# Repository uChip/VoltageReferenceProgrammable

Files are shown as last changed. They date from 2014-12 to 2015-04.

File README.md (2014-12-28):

Programmable Voltage Reference  
==============================

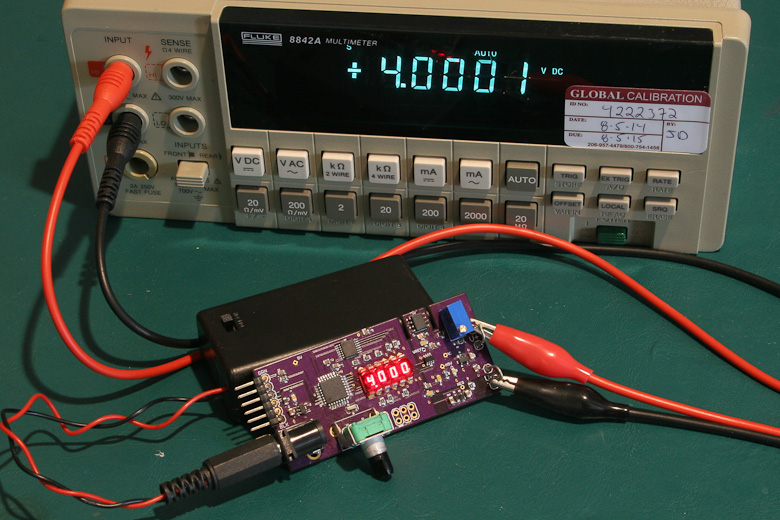
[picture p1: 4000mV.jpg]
Programmable Voltage Reference with 1 mV resolution and 100 uV accuracy
  
This repository contains the design files and write-up for a Programmable Voltage Reference.  The reference has a range of 1 mV to 4.095 volts in 1 mV steps.  The accuracy is plus or minus 100 uV for any set value.  The reference value is displayed on a 4 digit LED display and can be set manually using the rotary encoder or remotely over serial (FTDI port).

The software folder contains an Arduino sketch that is source code for the voltage reference firmware.

See the file PVR.pdf for a more detailed explanation of the project design. 

If there is sufficient interest I will build and calibrate a batch of these to sell.  If you would like one, please contact me. 

## Order PCBs  

You can order this PCB directly from OSH Park.  Click on the following link.  
  * Programmable Voltage Reference - https://oshpark.com/shared_projects/aFUNW4O5 

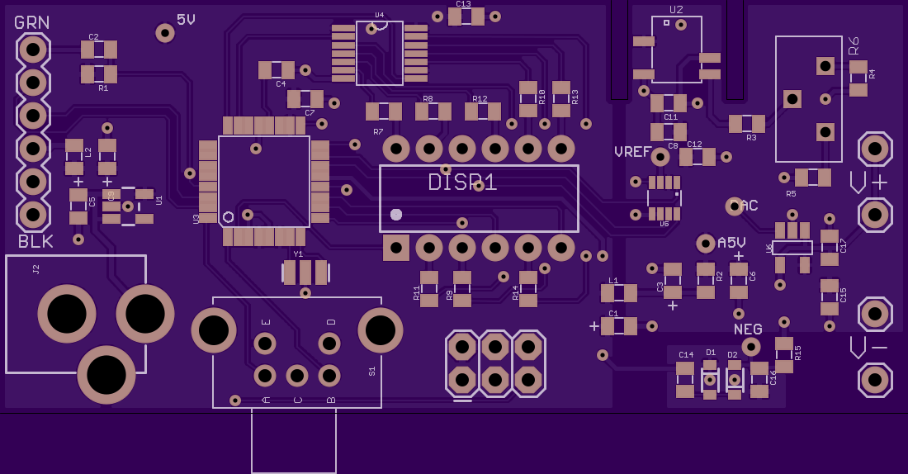
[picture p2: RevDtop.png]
PCB Top


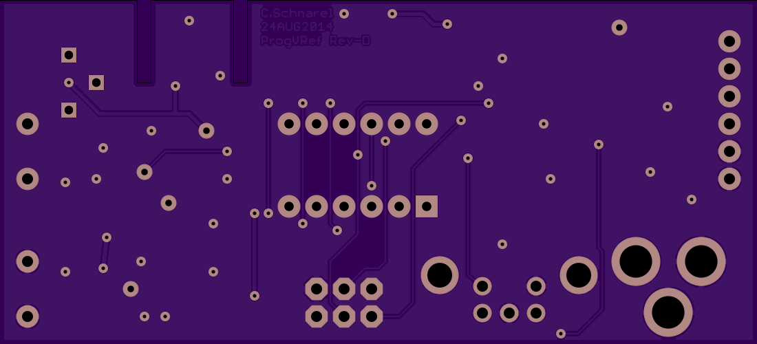
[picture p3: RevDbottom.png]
PCB Bottom


See the Bill of Materials (BOM) file in the repo Hardware folder for a parts list.  

## Status  
  * Rev-D PCB has been tested to be functional.  

## File Formats  

Hardware design files are in "CadSoft EAGLE PCB Design Software" .brd and .sch formats.  A free version of the software can be downloaded from www.cadsoftusa.com. 

The example code is in Arduino .ino format (text).  A free version of the Arduino software can be downloaded from www.arduino.cc.  

## Distribution License  

License:
<br /><span xmlns:dct="http://purl.org/dc/terms/" property="dct:title">Programmable Voltage Reference</span> by <a xmlns:cc="http://creativecommons.org/ns#" href="https://github.com/uChip/VoltageReferenceProgrammable" property="cc:attributionName" rel="cc:attributionURL">C.Schnarel</a> is licensed under a <a rel="license" href="http://creativecommons.org/licenses/by-sa/4.0/">Creative Commons Attribution-ShareAlike 4.0 International License</a>.

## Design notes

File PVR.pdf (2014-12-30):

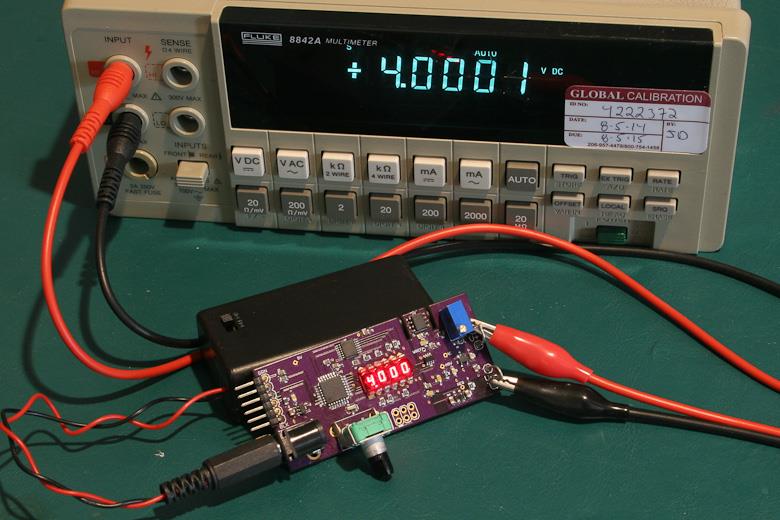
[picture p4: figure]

Programmable Voltage Reference with 1 mV resolution and 100 uV accuracy

Over the last few months I've done a few projects that made use of the analog inputs on the Arduino/ATmega processor. I found that trying to debug the software at the same time as debugging and calibrating the hardware was cumbersome (to put it mildly). The more I dealt with this, the more I thought that a programmable voltage reference would simplify things. With a programmable reference I could simulate an analog sensor input and debug the software without worrying about whether the sensor hardware is working or not. The voltage reference makes it easier to manipulate the input, test boundary conditions or check the accuracy of the ADC.

Consider this example of a simple temperature probe. The probe uses an ATtiny85 8-pin processor connected to an LMT84 analog temperature sensor and two LEDs, one red and one green. As long as the temperature stays in range the green LED flashes once every 15 seconds. If the temperature goes out of range, either high or low, for more than a few samples the red LED flashes instead until the unit is reset. The whole thing is powered by a coin cell and physically is about the size of the cell holder and twice as thick. The battery needs to last for a few months.

The design is simple, but has a couple of tricky aspects. How do you debug a processor that has no serial port and is asleep most of the time? There weren't even any spare pins to send out debug signals. The processor controls the power to the sensor so that's not on all the time either. The sensor is putting out a signal only one millisecond out of every 15,000. Measuring that is a tough job for a DMM or for my old analog scope. And even if you assume the sensor is working perfectly how do you manipulate the sensor accurately to test the range thresholds?

By substituting a voltage reference for the sensor the development is simplified. By supplying a known voltage to the ADC input I can debug the software by writing test code to flash the LEDs and get the ADC working right. Once I know I'm getting good readings I can then vary the reference input through a range of values to check that the software handles all input values correctly and triggers when it should. Once I know the ADC is reading correctly and the software is doing the right thing with the ADC values, I can put the sensor back in the circuit and verify it using the software.

So having decided that a voltage reference would be a good thing to have, I looked around on eBay and other places. I don't seem to have Dave Jones' eBay luck. (http://www.eevblog.com/2011/10/24/eevblog-210-krohn-hite-dc-voltage-standard-teardown-calibration/) Everything I could find was hundreds of dollars. I don't have that much to spend, so instead I decided to build my own.

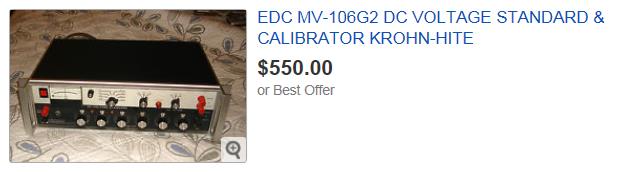
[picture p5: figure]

Example Voltage Standard posting on eBay

I need to go on a tangent here for a moment. I keep using the term voltage reference. If you do a search for voltage reference on eBay, or your favorite parts supplier, you will get lots of hits and what you find will cost only a few dollars. However, most of these provide only a single voltage and have accuracies in the 0.05% range. That means that at 4 volts they could be off by as much as 2 mV. I’d like something that is accurate to at least 100 uV or about twenty times better. The things that I’m talking about and what Dave Jones has are called voltage standards and can be set for many different values. The difference is that a voltage standard has been calibrated to a particular accuracy specification using an instrument that has been certified to have an even higher accuracy (typically ten times higher accuracy). And that instrument has been calibrated by an instrument certified to higher accuracy yet. This “chain of trust” goes back all the way to some standards body that holds the absolute gold standard for that particular chain. The best meter that I own is a 5 ½ digit (200,000 count) Fluke. It has been calibrated by a certified calibration lab so I have access to that chain of trust. And while I think I can achieve the level of accuracy I want, it might be presumptuous of me to call my device a voltage standard. So I’ll keep calling it a reference even though I hope it behaves like and I can use it like a standard.

Getting back to the design of the device: The goal would be to set voltages with the same or better resolution than the ATmega's ADC input across a reasonable input range. Since the ADC is 10 bit it has 1024 levels. If you choose the band-gap reference for the ADC, that's roughly 1 millivolt resolution. If instead we choose AVcc as the reference the resolution would be ~5 mV (on a 5 V system), but let's shoot for 1 mV across the whole range. A nice round number for the range would be 4.095 volts. That's 12-bits worth of 1 mV steps. For accuracy, I'd like when I set the reference to 1.234 mV that it be significantly closer to that value than to 1.233 or 1.235. Same thing when I set the value to 0.005 or 4.095. Let's call it within 100 uV of the target value. Of course, accuracy and resolution are no good if there's too much noise, so it must be low noise as well. This is a voltage reference, not a power supply, so a limit of a few milliamps is acceptable. The last spec is budget. As I said voltage standards on eBay go for hundreds of dollars. I am targeting a budget of $50 parts cost.

A voltage reference is really a simple device. In fact it could be as simple as a potentiometer and an OpAmp. Hook the output of the OpAmp to a good voltmeter and set the voltage level you need using the pot. But that ties up the meter and setting the pot to millivolt values across a multi-volt scale is at best fiddly. So let's complicate things a bit. Let's make the selection digital and include a 4-digit LED display. If we build the control around an Arduino core, the software development is simpler, plus we can re-use the programming serial port for remote control.

Interestingly enough, though I've finished project already, I just recently watched Ian Johnson's video (http://ianjohnston.com/index.php?option=com_content&view=article&id=108) on hacking a voltage standard he bought on eBay. Inside his EDC 501J I expected to see a high end integrated precision DAC. Instead what was inside was a DAC built from discrete resistors and many more trim pots than I expected. The expense must have been in trimming all those resistors!

I want to be able to calibrate as well, but let's hold that to a single trim pot and do the rest in software. For the core of my design I chose the REF5040ID voltage reference chip paired with the AD5060BRJZ DAC. I chose the 5040 because it starts with good accuracy, good temperature stability, good aging and is trimmable. The 5040 is accurate to 0.05% or about 2 mV, but has a trim input. By using a trimmable reference I should be able to get the error well under 1 mV. The 5060 is a 16-bit DAC with plus or minus 2 LSB relative accuracy (INL) and 1 LSB differential nonlinearity (DNL). If you recall, the output resolution needs to be 12 bits. By using a 16-bit DAC the output can be set to the proper 12-bit value and then calibrated with another 4 bits. If the 12-bit step is 1 mV then 4 more bits is 1/16 or 0.0625 mV which should enable me to calibrate to well within the spec. Note that together these two parts are over $20. They are relatively expensive compared to the microcontroller, display or even the PCB, but since they also are the heart of the device I think they are worth it.

All of the rest of the circuitry is there to provide the control interface and to support those two chips. There is a voltage-follower OpAmp driving the output. The OpAmp doesn’t have any more drive than the DAC itself, but it’s better to expose the output of a $2 part rather than a $13 part. The display is a 4 digit 7 segment LED that I have used before. The control knob is a rotary encoder with push button. Turning the encoder right or left steps the output up or down by 1 mV. Pressing the encoder knob push button jumps the output by 250 mV. The output steps up to a max value of 4.095 mV and then rolls around to its lowest setting of 1 mV. In the other direction stepping down past 1 mV rolls around again to 4.095 V. This allows any valid value to be set without too much work. The device will also accept an ASCII string on the serial port to set the voltage level.

To answer some anticipated questions:

- Why doesn't the output go to 0 V? I wanted to power the device from battery or USB and to keep the cost down I wanted it to be a single-ended supply. But a single-ended supply means that devices that drive voltage have a hard time getting all the way to ground so I allowed a 1 mV minimum to ease the design. Besides if you really need 0 volts you can remove the voltage reference and ground that signal.

You can even ground the output with the voltage reference still in the circuit (the output will not be damaged according to the OpAmp spec) but I advise against it.

- Why doesn't the output go to 5 V? Most of the sensors I’m working with are powered by 3.3 V, so a range of 4.095 V is more than adequate. By powering the voltage reference from USB I have only 5V (plus or minus 10%) available and the reference chip needs a few hundred millivolts of headroom to do its work. Plus by using a 4.096 volt reference, the math for the project is simplified. I could have used a boost regulator but that would have added more cost. If I had chosen a 5 V reference I would have also needed to go to a more expensive 17 or 18 bit DAC to meet the resolution and accuracy spec.

The circuit is burned in for 250 hours before calibrating and the reference is trimmed to as close to 4.096 V as I can make it. Then to calibrate the DAC I wrote a program to set each valid 12-bit value on the DAC and then read it back from the Fluke’s GPIB port. From these I compute a correction factor for that value which gets stored in the microcontrollers EEPROM memory. Since there is not enough EEPROM to store all 4096 correction factors they are run-length encoded before being stored.

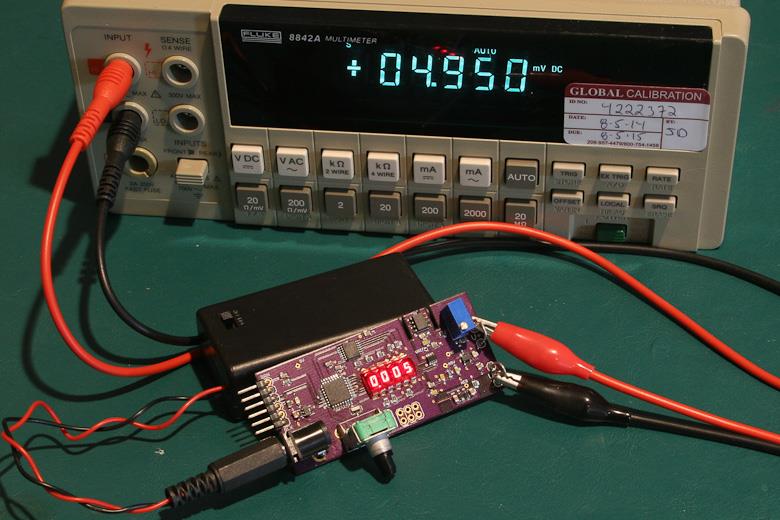
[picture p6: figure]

PVR set to 5 mV shows accurate to 50 uV

That's about it. You can see a fair number of capacitors and a couple inductors in the schematic. Those are to prevent and reduce signal noise. The rest of the circuit is pretty straight forward.

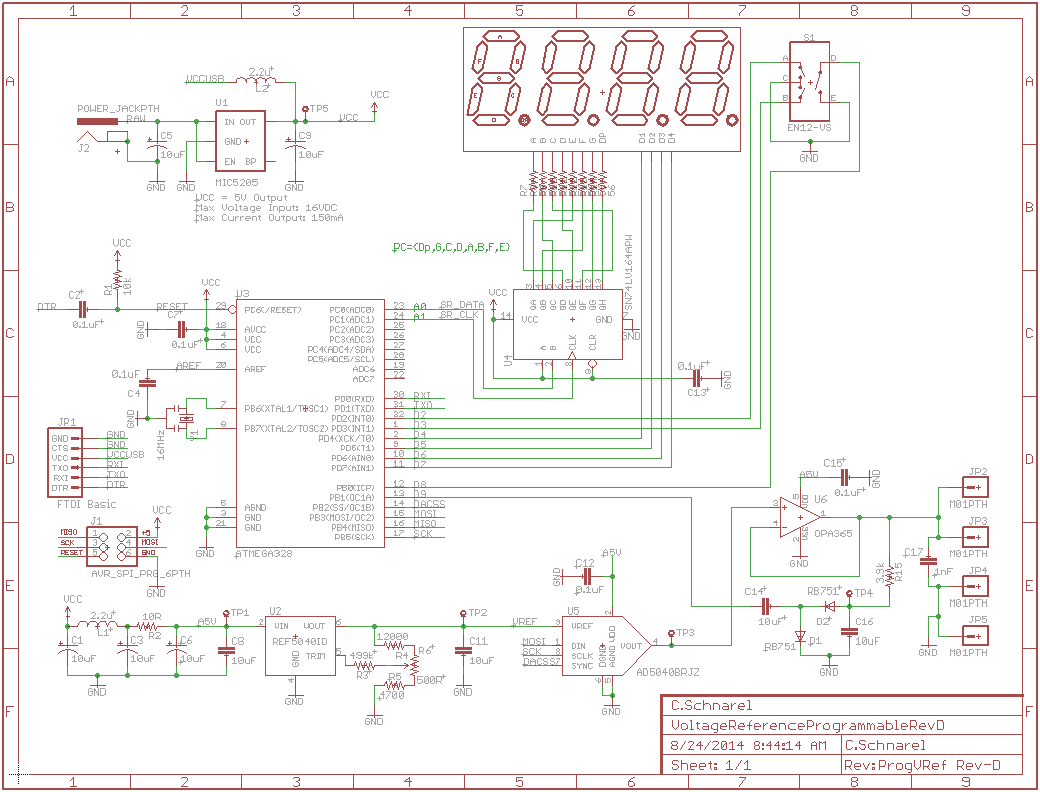
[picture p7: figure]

So how well does it work? Let's review the specs.

- Range: 1 to 4095 mV. By design. Check
- Resolution: 1 mV steps. By design. Check
- Accuracy: For values in the range of 1 to 1.999 V I’m measuring 50 uV accuracy. Unfortunately at that point my 200,000 count meter hits its own limits and I can only measure to plus or minus 100 uV, but I believe with a better meter I could calibrate to better than 50 uV across the full range. Even at plus or minus 100 uV the spec has been met.
- Noise: I have never seen more jitter than the least significant digit on the DMM even when the meter range is down in the microvolts. I don’t have a quantitative measure, but the output seems pretty quiet.
- Current: Loading the output with a 1k resistor does not change the output voltage but heavier loading quickly starts affecting the output. A few milliamps of drive is all we designed in so it’s not surprising that’s all we get.
- Cost: the total parts cost including PCB was $43.89.

Is it useful? Unquestionably yes. I find myself reaching for this tool whenever I'm building a circuit with an ADC or writing the associated code. It is very valuable to have a reliable reference that I can check against or that can fill in for a sensor or other signal source in a controllable, reliable and repeatable way. I highly recommend it.

As usual you can find the schematic, board layout, parts list and source code on my Github site. (https://github.com/uChip/VoltageReferenceProgrammable) Or I'm contemplating selling (assembled, tested and calibrated) a batch of these to earn myself a new scope and/or better DMM. If you are interested in having one, let me know.

Good luck with your projects!

- Chip

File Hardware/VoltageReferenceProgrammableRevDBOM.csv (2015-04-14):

NOTE: Altitude on the SparkFun forum points out that the pads for the 0805 parts below are small for hand soldering and that substituting 0603 parts where possible actually makes assembly easier. If this works for you, there is no functional downside to using the 0603 parts. Thx. - CS
Qty;"Value";"Device";"Package";"Parts";"Description";"CNAME";"CREVISION";"DATECODE";"DESIGNER";
6;"0.1uF";"CAP0805";"0805";"C2 | C4 | C7 | C12 | C13 | C15";"Capacitor";"";"";"";"";
1;"10R";"RESISTOR0805-RES";"0805";"R2";"Resistor";"";"";"";"";
1;"10k";"RESISTOR0805-RES";"0805";"R1";"Resistor";"";"";"";"";
4;"10uF";"CAP0805";"0805";"C8 | C11 | C14 | C16";"Capacitor";"";"";"";"";
5;"10uF";"CAP_POL0805";"0805-POL";"C1 | C3 | C5 | C6 | C9";"";"";"";"";"";
1;"12000";"RESISTOR0805-RES";"0805";"R4";"Resistor";"";"";"";"";
1;"16MHz";"RESONATORSMD";"RESONATOR-SMD";"Y1";"Resonator";"";"";"";"";
1;"1nF";"CAP0805";"0805";"C17";"Capacitor";"";"";"";"";
2;"2.2u";"INDUCTOR";"0805";"L1 | L2";"Inductor | SMT chip | 0805 pkg";"";"";"";"";
1;"3.9k";"RESISTOR0805-RES";"0805";"R15";"Resistor";"";"";"";"";
1;"4700";"RESISTOR0805-RES";"0805";"R5";"Resistor";"";"";"";"";
1;"499k";"RESISTOR0805-RES";"0805";"R3";"Resistor";"";"";"";"";
1;"500R";"TRIMPOT";"T93YB";"R6";"Various small potentiometers for "set-and-forget" applications";"";"";"";"";
8;"56";"RESISTOR0805-RES";"0805";"R7 | R8 | R9 | R10 | R11 | R12 | R13 | R14";"Resistor";"";"";"";"";
1;"AD5060BRJZ";"AD5060BRJZ";"SOT-23-8";"U5";"";"";"";"";"";
1;"ATMEGA328";"ATMEGA168";"TQFP32-08";"U3";"";"";"";"";"";
1;"AVR_SPI_PRG_6PTH";"AVR_SPI_PRG_6PTH";"2X3";"J1";"AVR ISP 6 Pin";"";"";"";"";
1;"EN12-VS";"EN12-VS";"ROTARY_ENCODER_SIDE";"S1";"Rotary Encoder w push switch | quadrature | 12 pulse/rev. BI Technologies. Digi-key#987-1198-ND";"";"";"";"";
1;"FRAME_LTR_CU_MARK";"FRAME_LTR_CU_MARK";"FR-LTR-ON-PCB";"FRAME1";"This frame is sized for an 8.5x11" page with a 0.25" margin. It also places a name | datecode and revision mark in the bottom copper layer of the PCB.";"C.Schnarel";"ProgVRef Rev-D";"24AUG2014";"C.Schnarel";
1;"FTDI Basic";"ARDUINO_SERIAL_PROGRAMPTH";"1X06";"JP1";"";"";"";"";"";
4;"M01PTH";"M01PTH";"1X01";"JP2 | JP3 | JP4 | JP5";"Header 1";"";"";"";"";
1;"MIC5205";"V_REG_LDOSMD";"SOT23-5";"U1";"Voltage Regulator LDO";"";"";"";"";
1;"OPA365";"OPA365";"SOT-23-5";"U6";"OpAmp | 50MHz | R-to-R | single-supply | CMOS | TI | Digi-Key#296-20645-1-ND";"";"";"";"";
1;"POWER_JACKPTH";"POWER_JACKPTH";"POWER_JACK_PTH";"J2";"Power Jack";"";"";"";"";
2;"RB751";"DIODESOD";"SOD-323";"D1 | D2";"Diode";"";"";"";"";
1;"REF5040ID";"REF5040ID";"SOIC-8-MINUSPINS";"U2";"";"";"";"";"";
1;"SN74LV164APW";"SN74LV164APW";"TSSOP-14(TI)";"U4";"8-BIT SERIAL-IN PARALLEL-OUT SHIFT REGISTER with clear";"";"";"";"";
5;"TEST_POINT";"TEST_POINT";"BBD-VIA";"TP1 | TP2 | TP3 | TP4 | TP5";"Test Point";"";"";"";"";
1;"hp";"7-SEGMENT-4DIGIT-COUNTER-HP-BUBBLE";"DIL12";"DISP1";"";"";"";"";"";

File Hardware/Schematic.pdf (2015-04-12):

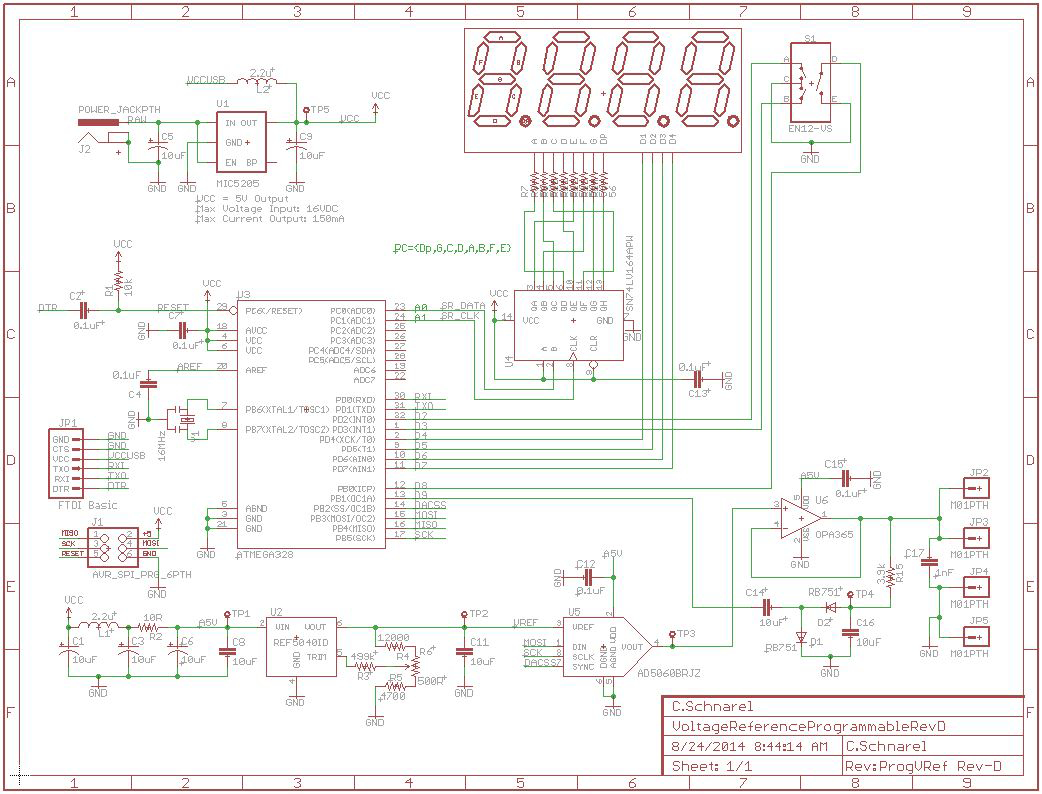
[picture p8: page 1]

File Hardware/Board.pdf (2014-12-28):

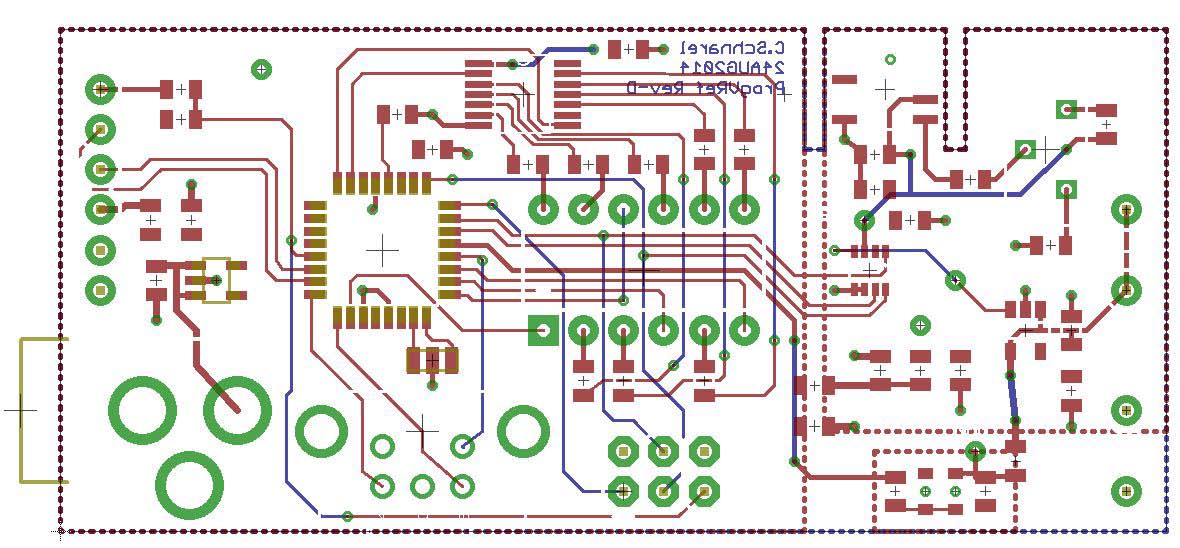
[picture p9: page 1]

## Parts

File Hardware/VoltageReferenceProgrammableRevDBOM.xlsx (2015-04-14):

NOTE: Altitude on the SparkFun forum points out that the pads for the 0805 parts below are small for hand soldering and that substituting 0603 parts where possible actually makes assembly easier. If this works for you, there is no functional downside to using the 0603 parts. Thx. - CS
Qty | @ Cost | Total | Value | Device | Package | Parts | Description | CNAME | CREVISION | DATECODE | DESIGNER
6 | 0.0141 | $0.08 | 0.1uF | CAP0805 | 805 | C2, C4, C7, C12, C13, C15 | Capacitor
1 | 0.0122 | $0.01 | 10R | RESISTOR0805-RES | 805 | R2 | Resistor
1 | 0.0162 | $0.02 | 10k | RESISTOR0805-RES | 805 | R1 | Resistor
4 | 0.0499 | $0.20 | 10uF | CAP0805 | 805 | C8, C11, C14, C16 | Capacitor
5 | 0.8370 | $4.18 | 10uF | CAP_POL0805 | 0805-POL | C1, C3, C5, C6, C9
1 | 0.0381 | $0.04 | 12k | RESISTOR0805-RES | 805 | R4 | Resistor
1 | 0.4000 | $0.40 | 16MHz | RESONATORSMD | RESONATOR-SMD | Y1 | Resonator
1 | 0.0385 | $0.04 | 1nF | CAP0805 | 805 | C17 | Capacitor
2 | 0.1040 | $0.21 | 2.2u | INDUCTOR | 805 | L1, L2 | Inductor, SMT chip, 0805 pkg
1 | 0.0071 | $0.01 | 3.9k | RESISTOR0805-RES | 805 | R15 | Resistor
1 | 0.0122 | $0.01 | 4.7k | RESISTOR0805-RES | 805 | R5 | Resistor
1 | 0.0084 | $0.01 | 499k | RESISTOR0805-RES | 805 | R3 | Resistor
1 | 1.6600 | $1.66 | 500R | TRIMPOT | T93YB | R6 | Various small potentiometers for set-and-forget" applications"
8 | 0.0071 | $0.06 | 120R | RESISTOR0805-RES | 805 | R7, R8, R9, R10, R11, R12, R13, R14 | Resistor
1 | 12.7700 | $12.77 | AD5060BRJZ | AD5060BRJZ | SOT-23-8 | U5
1 | 3.6100 | $3.61 | ATMEGA328 | ATMEGA168 | TQFP32-08 | U3
1 | 0.9440 | $0.94 | EN12-VS | EN12-VS | ROTARY_ENCODER_SIDE | S1 | Rotary Encoder w push switch, quadrature, 12 pulse/rev. BI Technologies. Digi-key#987-1198-ND
1 | 0.5760 | $0.58 | MIC5205 | V_REG_LDOSMD | SOT23-5 | U1 | Voltage Regulator LDO
1 | 1.6850 | $1.69 | OPA365 | OPA365 | SOT-23-5 | U6 | OpAmp, 50MHz, R-to-R, single-supply, CMOS, TI, Digi-Key#296-20645-1-ND
1 | 0.6440 | $0.64 | POWER_JACKPTH | POWER_JACKPTH | POWER_JACK_PTH | J2 | Power Jack
2 | 0.1872 | $0.37 | RB751 | DIODESOD | SOD-323 | D1, D2 | Diode
1 | 7.3100 | $7.31 | REF5040ID | REF5040ID | SOIC-8-MINUSPINS | U2
1 | 0.3680 | $0.37 | SN74LV164APW | SN74LV164APW | TSSOP-14(TI) | U4 | 8-BIT SERIAL-IN PARALLEL-OUT SHIFT REGISTER with clear
1 | 2.9500 | $2.95 | hp | 7-SEGMENT-4DIGIT-COUNTER-HP-BUBBLE | DIL12 | DISP1
1 | 5.7333 | $5.73 | PCB
 |  | $43.89 | Total Parts Cost

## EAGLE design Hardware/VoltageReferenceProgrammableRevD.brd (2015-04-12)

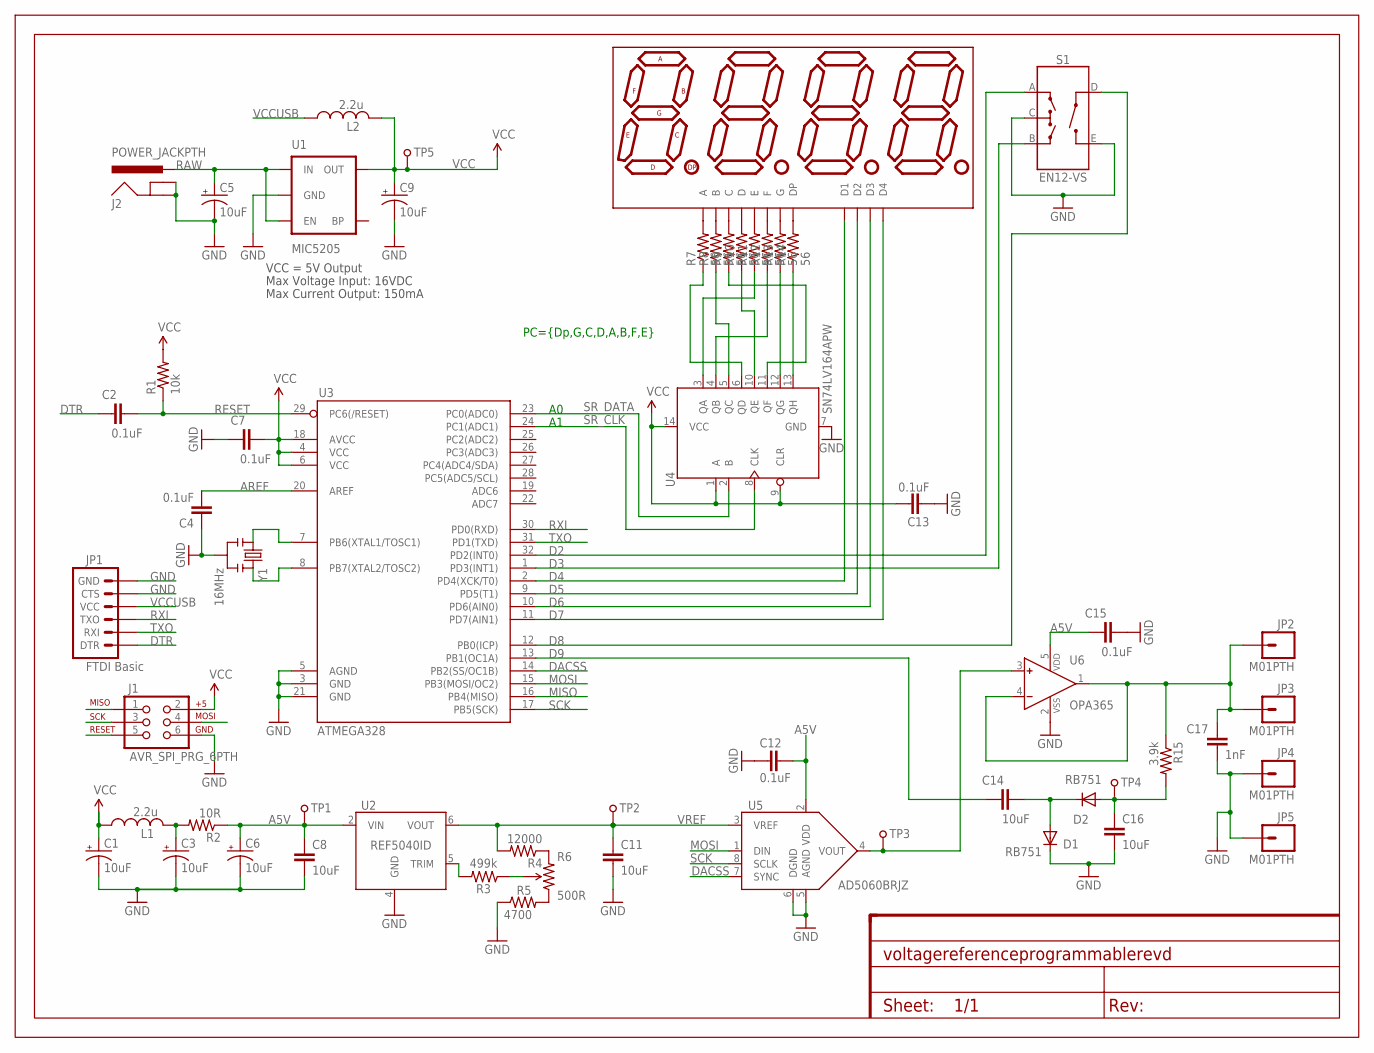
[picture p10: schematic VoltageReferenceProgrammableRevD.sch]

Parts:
C1, C3, C5, C6, C9: 10uF; 0805-POL
C2, C4, C7, C12, C13, C15: 0.1uF; 0805
C8, C11, C14, C16: 10uF; 0805
C17: 1nF; 0805
D1, D2: RB751; SOD-323
DISP1: hp; DIL12
FRAME1: FRAME_LTR_CU_MARK; FR-LTR-ON-PCB
J1: AVR_SPI_PRG_6PTH; 2X3
J2: POWER_JACKPTH; POWER_JACK_PTH
JP1: FTDI Basic; 1X06
JP2, JP3, JP4, JP5: M01PTH; 1X01
L1, L2: 2.2u; 0805
R1: 10k; 0805
R2: 10R; 0805
R3: 499k; 0805
R4: 12000; 0805
R5: 4700; 0805
R6: 500R; T93YB
R7, R8, R9, R10, R11, R12, R13, R14: 56; 0805
R15: 3.9k; 0805
S1: EN12-VS; ROTARY_ENCODER_SIDE
TP1, TP2, TP3, TP4, TP5: TEST_POINT; BBD-VIA
U1: MIC5205; SOT23-5
U2: REF5040ID; SOIC-8-MINUSPINS
U3: ATMEGA328; TQFP32-08
U4: SN74LV164APW; TSSOP-14(TI)
U5: AD5060BRJZ; SOT-23-8
U6: OPA365; SOT-23-5
Y1: 16MHz; RESONATOR-SMD

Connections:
A5V: C6.1 (+), C8.1, C12.1, C15.1, R2.1, TP1.P$1, U2.2 (VIN), U5.2 (VDD), U6.5 (VDD)
ADCIN: C16.1, D2.2 (A), R15.2, TP4.P$1
AREF: C4.2, U3.20 (AREF)
D2: S1.A, U3.32 (PD2(INT0))
D3: S1.B, U3.1 (PD3(INT1))
D4: DISP1.1 (D1), U3.2 (PD4(XCK/T0))
D5: DISP1.10 (D2), U3.9 (PD5(T1))
D6: DISP1.4 (D3), U3.10 (PD6(AIN0))
D7: DISP1.6 (D4), U3.11 (PD7(AIN1))
D8: S1.D, U3.12 (PB0(ICP))
D9: C14.1, U3.13 (PB1(OC1A))
DACSS: U3.14 (PB2(SS/OC1B)), U5.7 (SYNC)
DTR: C2.1, JP1.1 (DTR)
GND: C1.2 (-), C3.2 (-), C4.1, C5.2 (-), C6.2 (-), C7.1, C8.2, C9.2 (-), C11.2, C12.2, C13.2, C15.2, C16.2, C17.1, D1.1 (C), J1.6, J2.GND, J2.GNDBREAK, JP1.5 (CTS), JP1.6 (GND), JP4.1, JP5.1, R5.1, S1.C, S1.E, U1.2 (GND), U2.4 (GND), U3.3 (GND), U3.5 (AGND), U3.21 (GND), U4.7 (GND), U5.5 (AGND), U5.6 (DGND), U6.2 (VSS), Y1.2
MISO: J1.1, U3.16 (PB4(MISO))
MOSI: J1.4, U3.15 (PB3(MOSI/OC2)), U5.1 (DIN)
unnamed: U3.7 (PB6(XTAL1/TOSC1)), Y1.1
unnamed: U3.8 (PB7(XTAL2/TOSC2)), Y1.3
unnamed: DISP1.12 (A), R7.2
unnamed: DISP1.11 (B), R8.2
unnamed: DISP1.3 (C), R9.2
unnamed: DISP1.8 (D), R10.2
unnamed: R14.1, U4.13 (QH)
unnamed: DISP1.2 (E), R11.2
unnamed: DISP1.9 (F), R12.2
unnamed: DISP1.7 (G), R13.2
unnamed: DISP1.5 (DP), R14.2
unnamed: TP3.P$1, U5.4 (VOUT), U6.3 (IN+)
unnamed: C17.2, JP2.1, JP3.1, R15.1, U6.1 (OUT), U6.4 (IN-)
unnamed: R3.1, R6.2 (WIPER)
unnamed: R13.1, U4.12 (QG)
unnamed: C14.2, D1.2 (A), D2.1 (C)
unnamed: R3.2, U2.5 (TRIM)
unnamed: R5.2, R6.1 (CCW)
unnamed: R4.1, R6.3 (CW)
unnamed: R9.1, U4.11 (QF)
unnamed: R10.1, U4.10 (QE)
unnamed: R7.1, U4.6 (QD)
unnamed: R8.1, U4.5 (QC)
unnamed: R12.1, U4.4 (QB)
unnamed: R11.1, U4.3 (QA)
unnamed: C3.1 (+), L1.2, R2.2
RAW: C5.1 (+), J2.PWR, U1.1 (IN), U1.3 (EN)
RESET: C2.2, J1.5, R1.1, U3.29 (PC6(/RESET))
RXI: JP1.3 (TXO), U3.30 (PD0(RXD))
SCK: J1.3, U3.17 (PB5(SCK)), U5.8 (SCLK)
SR_CLK: U3.24 (PC1(ADC1)), U4.8 (CLK)
SR_DATA: U3.23 (PC0(ADC0)), U4.2 (B)
TXO: JP1.2 (RXI), U3.31 (PD1(TXD))
VCC: C1.1 (+), C7.2, C9.1 (+), C13.1, J1.2, L1.1, L2.2, R1.2, TP5.P$1, U1.5 (OUT), U3.4 (VCC), U3.6 (VCC), U3.18 (AVCC), U4.1 (A), U4.9 (CLR), U4.14 (VCC)
VCCUSB: JP1.4 (VCC), L2.1
VREF: C11.1, R4.2, TP2.P$1, U2.6 (VOUT), U5.3 (VREF)

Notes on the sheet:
Max Voltage Input: 16VDC
Max Current Output: 150mA
VCC = 5V Output
PC={Dp,G,C,D,A,B,F,E}

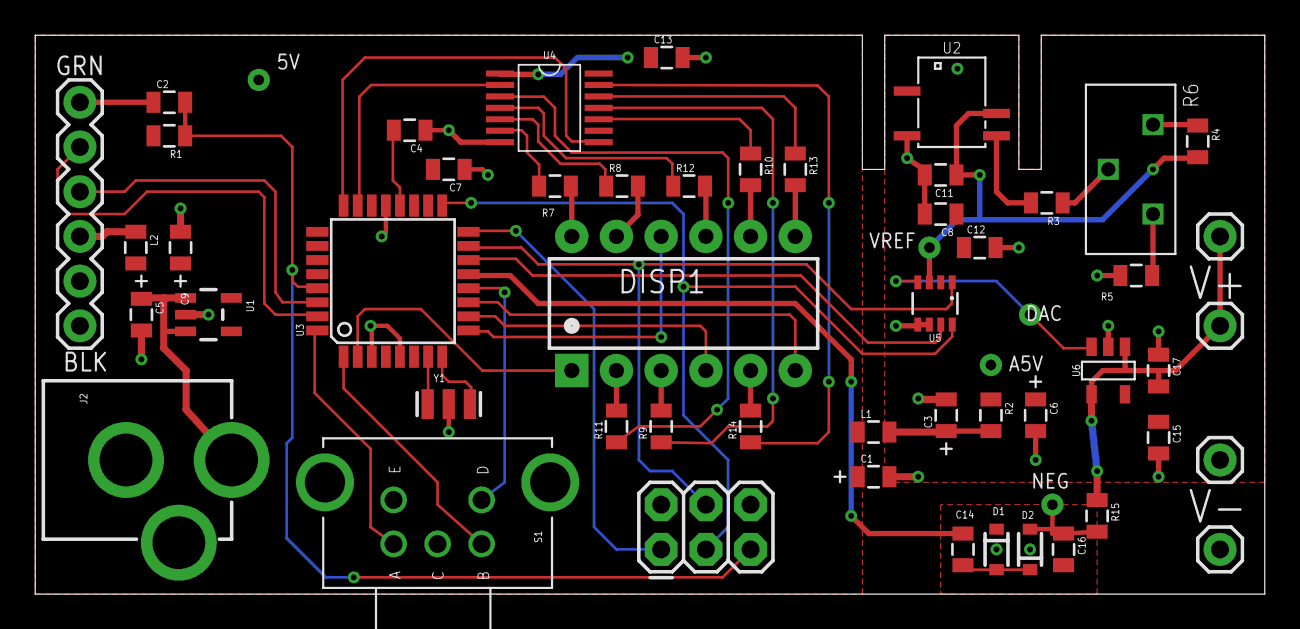
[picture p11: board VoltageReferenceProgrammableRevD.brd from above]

Board: 2 copper layers, 69.8 x 31.8 mm, 57 parts (0 on the bottom side), 52 nets.

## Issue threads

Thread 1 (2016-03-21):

Calibration Process.

bohunter11, 2016-03-21:
I have no issues other than this is the only way I knew how to get in contact with you.
I'm looking trough the code and can't wrap my head around the offset correction factor
process. If you could help me I would be very grateful. The pdf file talks about rle but
I don't see where this is being done.

Thank you,
Bo Hunter
email is
bhunter
at
hunterserver
.com

uChip, 2016-03-21:
Responded with my email.

bohunter11, 2016-03-21:
I can’t quite make it to 4.096, the 500 ohm trimmer won’t get me there.
This is with fluke 8808a. and I used 1% for R3,4,5. What do you suggest?

Thank You
Bo Hunter
Cell: 828-699-4324

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

Closed 2016-03-21.

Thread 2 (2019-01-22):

10V ref suggestion

alex1sh, 2019-01-22:
Hello,

Thanks for an excellent project first of all and apologies for writing into "issues" section.
I wonder if it is possible to modify your reference to be able to have voltage from 0 to 10V.
I think it would be a much more useful range. What would you suggest to modify?
I'll probably use ref102 10V Vref or a more precise 10V LM399.

Another improvement could be using a TFT 3.5" display to set voltage output rather than using a potentiometer. I have already made some progress on this.

Thank you.
Alex

uChip, 2019-01-22:
Every design is a collection of engineering trade offs.  You can certainly do a 10V reference.  In fact there are several designs already published.  One of my favorites is the one done by Ian Johnston https://www.youtube.com/watch?v=f4E10GpvfZs  Since most of my work is with low voltage devices (Arduino, Raspberry Pi) the 5V range fit my needs better.  But feel free to fork my design and change or elaborate as you like.
Thanks for your kind words and have fun with your project!
  - Chip

alex1sh, 2019-01-24:
Yes, I have been following Ian since he started constructing his Vref. I even had a chat with him recently about it on the eevblog. My idea however is slightly different. I do want to build a vref with a touch display driven by atmega2560 or similar IC. I have the interface reading though I am sure it is going to evolve. Now I am testing different vref IC. I really liked ref102. Alternatively, I may use just like Ian LM399. I have one currently being aged.

Thanks
Alex

Closed 2019-01-22.

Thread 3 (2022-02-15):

Function of the chargepump on PB9

dirkx, 2022-02-15:
What is the function of the 50% pwm chargepump added to the output ? For anti-aliasing ?

With kind regards,

Dw

uChip, 2022-02-15:
It's been a while since I did this design, but if memory serves the pump provides a small negative bias at the output to help with opamp linearity at low voltages.

Closed 2022-02-15.

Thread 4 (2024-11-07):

Parts substitution

Electricman308, 2024-11-07:
Hi uChip,
I am in the process of building your VoltageReferenceProgrammable - thank you for sharing this project!
The boards are on their way to me and I am sourcing all the components. The issue I am having is I cannot seem to source "7-SEGMENT-4DIGIT-COUNTER-HP-BUBBLE" it seems to have been discontinued. Do you have any recommendations as to what I can use instead? I cannot find any other DIL12 package 4 digit 7 segment LED displays.
Thanks from Australia!

Electricman308, 2024-11-19:
Hi uChip,
I have found a workaround replacement - won't be as neat as have already got the boards printed but should do the job. Thanks for your work on this project! Looking forward to completing my rendition!
Thanks

Electricman308, 2024-11-19:
If anyone else is chasing a replacement, ask me how it went - hopefully I'll have it completed by then. :-)
Cheers

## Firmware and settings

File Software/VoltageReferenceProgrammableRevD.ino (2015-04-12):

// Include libraries this sketch will use
//#include <ProfileTimer.h>  // this library was used in development to set display refresh.  No longer used.
#include <SPI.h>             // part of Arduino distribution
#include <EEPROM.h>          // part of Arduino distribution
#include <Rotary.h>          // https://github.com/brianlow/Rotary
#include <Bounce2.h>         // http://playground.arduino.cc/Code/Bounce

// Defines
// DAC Maximum value
#define MAXVAL 4095
// Maximum number of offset table entries
#define MAX_OFFSETS 10

// Pins to drive Segment Shift Register
#define SR_DATA A0
#define SR_CLK A1

// Display digit pins
#define DIGIT_1 4
#define DIGIT_2 5
#define DIGIT_3 6
#define DIGIT_4 7

// Charge pump pin
#define CHARGE_PUMP 9

// UI Rotary Encoder w Button
#define BUTTON 8

// DAC Slave Select
#define DACSS 10

// This sets the delay time for frame rate
// The value is repeated for each of the digits on the display so 
//   frame rate = 1 / (4 * DIGIT_TIME(uS)) -> 125 Hz
#define DIGIT_TIME 2000

// Mode values
// send refVal to DAC after adding correction factor
#define CORRECTED true
// send raw refVal numbers to the DAC w/o correcting
#define RAW false

// Character generator for 7-segment displays
static uint8_t	chargen[] = {
// PC={Dp,G,C,D,A,B,F,E} Segments scrambled to ease PCB layout
  0b00111111,  // 0
  0b00100100,  // 1
  0b01011101,  // 2
  0b01111100,  // 3
  0b01100110,  // 4
  0b01111010,  // 5
  0b01111011,  // 6
  0b00101100,  // 7
  0b01111111,  // 8
  0b01111110,  // 9
  0b01101111,  // 10  "A"
  0b01110011,  // 11  "B"
  0b01011011,  // 12  "C"
  0b01110101,  // 13  "D"
  0b01011011,  // 14  "E"
  0b01001011,  // 15  "F"
};

// Instantiate objects used in this project
Rotary r = Rotary(2, 3);
Bounce button = Bounce();

int16_t  refVal = 1000;
uint8_t CmdArray[7];
uint8_t CmdArrayIdx = 0;
int16_t num = refVal;
int DispBCD = 0;
boolean newVal = true;
boolean mode = CORRECTED;  // when mode = CORRECTED then offset value is used
boolean useFlag = false;  // when true uses downloaded value of offset
uint8_t sdata;
uint16_t DACreg;
int8_t offset = 0;


//-=|=-=|=-=|=-=|=-=|=-=|=-=|=-=|=-=|=-=|=-=|=-=|=-=|=-=|=-=|=-=|
void setup() {
  // Initialize USB interface
  Serial.begin(115200);
  delay(2000);
  Serial.println("Voltage Reference");  // set up the segment control pins

  pinMode(CHARGE_PUMP, OUTPUT);
  analogWrite(CHARGE_PUMP, 128);

  pinMode(BUTTON, INPUT_PULLUP);
  button.attach(BUTTON);
  button.interval(5);
  button.update();
  if(button.read() == LOW) {mode = RAW;} else {mode = CORRECTED;}

  pinMode(SR_DATA, OUTPUT);
  pinMode(SR_CLK, OUTPUT);
  
  // set up the digit control pins
  pinMode(DIGIT_1, OUTPUT);
  pinMode(DIGIT_2, OUTPUT);
  pinMode(DIGIT_3, OUTPUT);
  pinMode(DIGIT_4, OUTPUT);
  
  // set up the select control pin for the DAC
  // DAC select is active low, data is shifted in MSB first
  // on the falling edge of the clock
  pinMode(DACSS, OUTPUT);
  digitalWrite(DACSS, HIGH);
  SPI.begin();
  SPI.setDataMode(SPI_MODE1);  // set to falling edge clock
  SPI.setBitOrder(MSBFIRST);  // set to MSB first
}

//-=|=-=|=-=|=-=|=-=|=-=|=-=|=-=|=-=|=-=|=-=|=-=|=-=|=-=|=-=|=-=|
void loop() {
  
    // Increment by 500 if the button was pressed
  // If the increment result is more than MAX just set result to zero
  if(button.update()) {
    if(button.read() == HIGH) {
      refVal+=500;
      if(refVal>MAXVAL)refVal=1;
      newVal = true;
    }
  }
  
  // Check the rotary and increment or decrement if it was turned
  // If the increment result is more than MAX roll over to zero
  // If the decrement goes below zero value will roll over to 65535 (unsigned word)
  //   In that case set to result to MAX value
  unsigned char result = r.process();
  if (result) {
    result == DIR_CW ? refVal-- : refVal++;
    if(refVal<1)refVal=MAXVAL;
    if(refVal>MAXVAL)refVal=1;
    newVal = true;
  }

  while (Serial.available())
  {
    sdata = Serial.read();
    switch (sdata){
    case 35: // '#'  set DAC with correction factor
    case 33: // '!'  set DAC with no correction factor
    case 'W': // 'W' write offset values to EEPROM
    case 'R': // 'R' dump the offset table (mostly for debug)
    case 'U': // 'U' use a temporary offset
      CmdArrayIdx = 0;
      CmdArray[CmdArrayIdx++] = sdata;
      break;
    case 10: // LF
    case 13: // CR
      CmdArray[CmdArrayIdx++] = sdata;
      if(ParseCommand())
        newVal = true;
      break;
    default:
      CmdArray[CmdArrayIdx++] = sdata;
      if(CmdArrayIdx>6) CmdArrayIdx = 6;
    }
  }  

  // If the value has changed, update the display and send 
  // the new value to the DAC and the serial port
  if(newVal) {
    Serial.println((float)refVal/1000, 3);
    
    // Convert the 12-bit DAC value into a 16-bit value plus
    // an optional signed 8-bit correction factor.
    
    // First look up the correction factor
    if(!useFlag){
      int i=0;
      for(i=0;i<MAX_OFFSETS;i++){
        Serial.print((int16_t)(EEPROM.read(i*3)<<8 | EEPROM.read(i*3+1)));
        Serial.print(":");
        Serial.println((int8_t)EEPROM.read(i*3+2));
        if(refVal>=(int16_t)(EEPROM.read(i*3)<<8 | EEPROM.read(i*3+1))) {offset = EEPROM.read(i*3+2);}
        else break;
      }
    }
    
    // Next shift the 12-bit value up 4 bits and add in the correction factor if desired.
    if(mode == CORRECTED) {
     Serial.println(offset);
     DACreg = (refVal<<4) + offset;
    }
    else {
      DACreg = (refVal<<4);
    }

    // Now write the 16-bit value out to the DAC
    digitalWrite(DACSS, LOW);
    SPI.transfer((uint8_t) 0);
    SPI.transfer((uint8_t)((DACreg>>8) & 0xFF));
    SPI.transfer((uint8_t)(DACreg & 0xFF));
    digitalWrite(DACSS, HIGH);
    
    newVal = false;  // set the flag to false again after updating the DAC
  }
  
  // Convert the binary reference value into decimal digits
  // then multiplex the display using the digits
  num = refVal;
  DispBCD = 0;
  while(num >= 1000){DispBCD++; num-=1000;}
  ShiftOut(chargen[DispBCD] | 0x80);
  digitalWrite(DIGIT_1, LOW);
  delayMicroseconds(DIGIT_TIME);
  digitalWrite(DIGIT_1, HIGH);

  result = r.process();
  if (result) {
    result == DIR_CW ? refVal-- : refVal++;
    if(refVal<1)refVal=MAXVAL;
    if(refVal>MAXVAL)refVal=1;
    newVal = true;
  }

  DispBCD = 0;
  while(num >= 100) {DispBCD++; num-=100;}
  ShiftOut(chargen[DispBCD]);
  digitalWrite(DIGIT_2, LOW);
  delayMicroseconds(DIGIT_TIME);
  digitalWrite(DIGIT_2, HIGH);

  result = r.process();
  if (result) {
    result == DIR_CW ? refVal-- : refVal++;
    if(refVal<1)refVal=MAXVAL;
    if(refVal>MAXVAL)refVal=1;
    newVal = true;
  }

  DispBCD = 0;
  while(num >= 10)  {DispBCD++; num-=10;}
  ShiftOut(chargen[DispBCD]);
  digitalWrite(DIGIT_3, LOW);
  delayMicroseconds(DIGIT_TIME);
  digitalWrite(DIGIT_3, HIGH);

  result = r.process();
  if (result) {
    result == DIR_CW ? refVal-- : refVal++;
    if(refVal<1)refVal=MAXVAL;
    if(refVal>MAXVAL)refVal=1;
    newVal = true;
  }

  ShiftOut(chargen[num]);
  digitalWrite(DIGIT_4, LOW);
  delayMicroseconds(DIGIT_TIME);
  digitalWrite(DIGIT_4, HIGH);
}


//-=|=-=|=-=|=-=|=-=|=-=|=-=|=-=|=-=|=-=|=-=|=-=|=-=|=-=|=-=|=-=|
void ShiftOut(uint8_t data) {
  digitalWrite(SR_DATA, (data & 0x80));
  digitalWrite(SR_CLK, LOW);
  digitalWrite(SR_CLK, HIGH);
  digitalWrite(SR_DATA, (data & 0x40));
  digitalWrite(SR_CLK, LOW);
  digitalWrite(SR_CLK, HIGH);
  digitalWrite(SR_DATA, (data & 0x20));
  digitalWrite(SR_CLK, LOW);
  digitalWrite(SR_CLK, HIGH);
  digitalWrite(SR_DATA, (data & 0x10));
  digitalWrite(SR_CLK, LOW);
  digitalWrite(SR_CLK, HIGH);
  digitalWrite(SR_DATA, (data & 0x08));
  digitalWrite(SR_CLK, LOW);
  digitalWrite(SR_CLK, HIGH);
  digitalWrite(SR_DATA, (data & 0x04));
  digitalWrite(SR_CLK, LOW);
  digitalWrite(SR_CLK, HIGH);
  digitalWrite(SR_DATA, (data & 0x02));
  digitalWrite(SR_CLK, LOW);
  digitalWrite(SR_CLK, HIGH);
  digitalWrite(SR_DATA, (data & 0x01));
  digitalWrite(SR_CLK, LOW);
  digitalWrite(SR_CLK, HIGH);
}

//-=|=-=|=-=|=-=|=-=|=-=|=-=|=-=|=-=|=-=|=-=|=-=|=-=|=-=|=-=|=-=|
// Takes the data from the array and generates a new value for the Reference
boolean ParseCommand() {

  uint8_t i = 0;
  uint16_t j = 0;
  boolean retVal = false;

  if(CmdArray[5] != 10 && CmdArray[5] != 13) {
    // Error in the command array.  Clear it and start over.
    for(i=0;i<7;i++)CmdArray[i] = 0;
    CmdArrayIdx = 0;
    return false;
  }
  
  for(i=1;i<5;i++){
    j = j*10 + (CmdArray[i]-48); // '0'==48
  }
  if(j>MAXVAL) j = MAXVAL;
  // Serial.println(j);

  switch (CmdArray[0]) {
    case 33: // '!'
      mode = RAW;
      refVal = j;
      retVal = true;
      break;
    case 35: // '#'
      mode = CORRECTED;
      refVal = j;
      retVal = true;
      break;
    case 'W':
      if(mode == RAW) {
        EEPROM.write(refVal, (byte)j);
        // Serial.print(refVal);
        // Serial.print(":");
        // Serial.println((byte)j);
      }
      retVal = false;
      break;
    case 'U':
      offset = (byte)j;
      useFlag = true;
      retVal = true;
      break;
    case 'N':
      mode = CORRECTED;
      useFlag = false;
      retVal = true;
      break;
    case 'R':
      for(i=0; i<MAX_OFFSETS*3; i++){
        Serial.println(EEPROM.read(i), HEX);
      }
    default:
      retVal = false;
  }

  for(i=0;i<7;i++)CmdArray[i] = 0;
  CmdArrayIdx = 0;
  return retVal;
}

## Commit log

2014-12-28 Saving PDFs of schematic and board
2015-04-12 Corrected error on schematic & BOM
    AD5040 was replaced with AD5060.
    [VoltageReferenceProgrammableRevD.brd, VoltageReferenceProgrammableRevD.sch, VoltageReferenceProgrammableRevDBOM.csv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]
2015-04-14 Updated BOM to note potential part subst
    to make assembly easier for some folks.
    [VoltageReferenceProgrammableRevDBOM.csv, VoltageReferenceProgrammableRevDBOM.xlsx]

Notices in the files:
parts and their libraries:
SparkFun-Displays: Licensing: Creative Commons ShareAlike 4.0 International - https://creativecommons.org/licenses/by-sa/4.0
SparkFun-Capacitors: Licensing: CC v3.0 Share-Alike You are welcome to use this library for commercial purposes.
